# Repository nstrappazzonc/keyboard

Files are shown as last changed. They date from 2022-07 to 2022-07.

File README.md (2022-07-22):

# Keyboard Matías

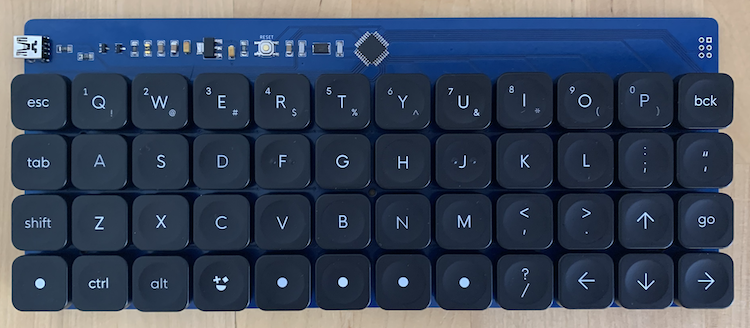
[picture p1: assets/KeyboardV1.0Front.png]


Es mi teclado Ortholinear diseñado y construido por mi, todo el hardware y el diseno es OpenSource (1), la idea de este repositorio es explicarte como se construye uno paso a paso.

1. Los MCU y otros componentes electronicos no son OpenSource.

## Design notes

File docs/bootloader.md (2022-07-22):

# Bootloader

La empresa [Microchip](https://www.microchip.com/) que fabrica el MCU ATmega32U2 que usamos para este proyecto, ofrece un [bootloader](https://www.microchip.com/en-us/product/ATMEGA32U2) que permite la funcionalidad DFU, también otros desarrolladores han hecho su propia versión cómo [Arduino](https://github.com/arduino/ArduinoCore-avr/tree/master/bootloaders) y [lufa](https://github.com/abcminiuser/lufa/tree/master/Bootloaders).

Un DFU quiere decir (Device Firmware Upgrade) y es un mecanismo desarrollado para ser implementado en los MCU, tienen una interfaz de conexión tipo USB para que puedan actualizar el firmware de una forma simple siempre y cuando éste pre-instalado. Con el DFU ya no hace falta flashear usando el ISP u otros medios.

Para tener el DFU en el MCU debemos flashearlo por la interfaz de conexion del ISP, una vez hecho ya no es necesario volver a usar el ISP en situaciones normales.

Para este proyecto, hemos dejado una [copia aquí](https://github.com/nstrappazzonc/keyboard/tree/main/firmware/bootloader).

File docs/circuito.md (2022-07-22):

# Circuito

En la alimentación por el puerto USB se ha implementado un circuito que evita la corriente devuelta (Reverse Current) mediante transistores MOSFET.

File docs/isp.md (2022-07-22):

# ISP

Significa In System Programmer o In-circuit Serial Programmer, y es una interfaz compuesta de 6 pines para programar el MCU.

ISP Pinout

Usando un [Pocket AVR Programmer](https://www.sparkfun.com/products/9825) podemos flashear el programa de nuestro ordenador al MCU mediante una aplicación llamada [avrdude](https://github.com/avrdudes/avrdude).

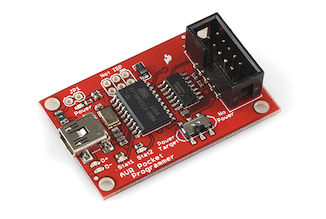
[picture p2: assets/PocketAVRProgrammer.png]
Pocket AVR Programmer


Lo que debe hacer es tener los 6 pines del ISP conectados al MCU de la siguiente forma:

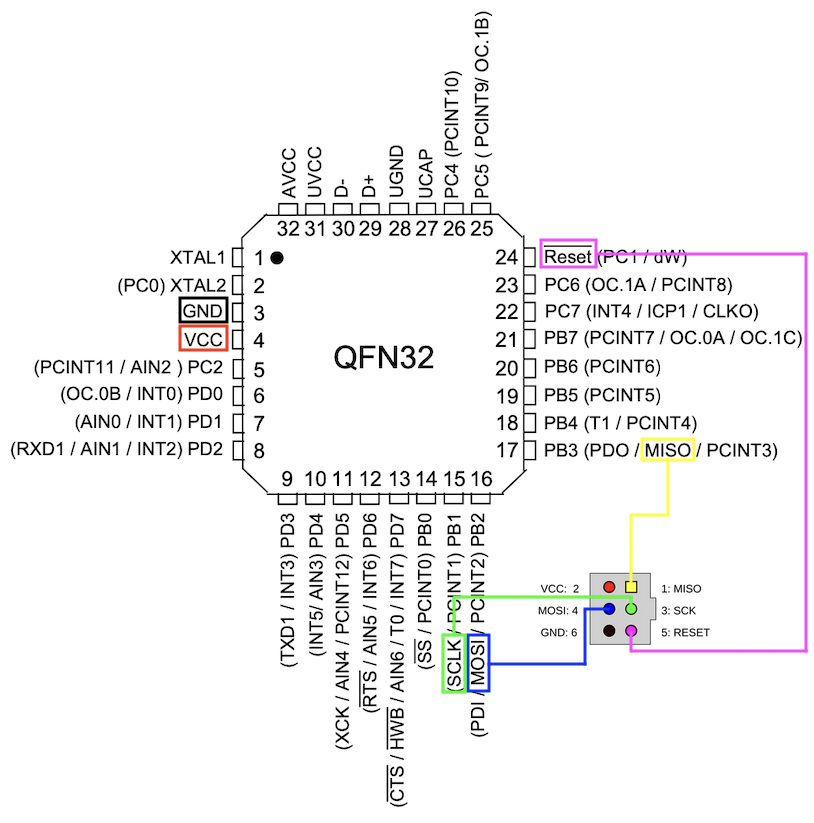
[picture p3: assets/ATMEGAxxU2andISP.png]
MCU & ISP


En MAC OS X y en Linux no hace falta drivers, al hacer `lsusb` me debería salir entre la lista el siguiente ID `1781:0c9f` del device conectado.

```bash
Bus 020 Device 013: ID 1781:0c9f 1781 Vendor-Specific Device
```

Para subir el firmware con el comando `avrdude` lo ejecutamos de la siguiente forma:

```bash
avrdude -c usbtiny -p ATMEGA32U2 -U flash:w:main.hex
```

De todos modos, en el proyecto hemos dejado todo listo dentro del [Makefile](https://github.com/nstrappazzonc/keyboard/blob/main/firmware/bootloader/Makefile) para subir el [DFU](https://github.com/nstrappazzonc/keyboard/blob/main/docs/bootloader.md).

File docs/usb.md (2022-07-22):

# USB

El conector USB instalado en el teclado es de tipo Mini B que esta compuesto de 5 pines, y el tipo de conector es de segunda generación o en su defecto Version 2.0, este tipo de conector soporta un radio de transferencia de 480 Mbps. y soporta un cable de hasta 5 metros de largo, lo cual es más que suficiente para un teclado convencional

Este tipo de conector necesita un cable compuesto de 4 hilos, cada uno tiene un proposito:

|Signal Name|Color |Description|
|---|---|---|
|GND |Negro |Ground |
|VCC |Rojo  |+5v |
|D+ / Dp |Verde |Data+ |
|D- / Dn |Blanco|Data- |

Cada extremo se conecta por igual, si el cable verde es D+ en uno de los extremos, tambien del otro extremo sigue siendo D-, no es cómo en otros protocolos que se invierte.

Las partes del cable tienen diferentes nombres, cada quien lo traduce o le asigna un nombre según la marca, pero es bastante intuitio:

1. **Cubierta del cable:** Llevan una cubierta de recubrimiento exterior de protección, por lo general son de material polimérico.
2. **Protección metalica:** Pueden estar compuesta de dos niveles, ambas de aluminio, ambos están desnudos a propósito, para que haga contacto entre ellos, cada uno tiene un proposito y juntas otro proposito:
    1. El trenzado es un blindaje mecanico que proteje el cable de agreciones externas; animales, golpes, etc.
    2. La pantalla es un aislante de las senales que pasan por el interior.
    3. Ambas protecciones tienen un uso adicional y es opcional en nuestro caso, el cual permite ser una conexion a tierra o una via de descarga electroestatica (ESD), donde el trenzado por su naturaleza debe conectarse (engarzado o soldado) a la carcasa metálica del receptáculo/enchufe USB al final del cable.
3. **Hilos:** Es el conductor de la senal, es un cable multifilar de cobre.

## Pinout

### USB Mini B Pinout:

| Male | Female |
|---|---|
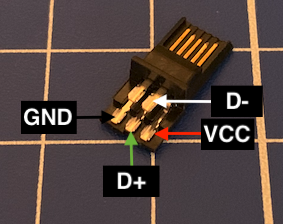
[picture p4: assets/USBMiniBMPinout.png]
USB Mini B Pinout
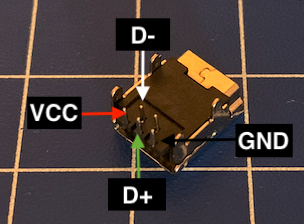
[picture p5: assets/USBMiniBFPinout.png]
USB Mini B Pinout
|||

### USB C Pinout:

| Male |
|------|
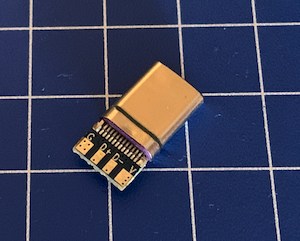
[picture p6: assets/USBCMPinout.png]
USB Mini B Pinout
||

Generalmente los conectores de este tipo ya viene impreso el significado del pin.

## Soldar

Leer los consejos antes de continuar, de esta forma podrás crear tu propio cable con mas facilidad y seguridad.

0. Revisar el estado de los cables y conectores, que no esten occidados.
1. Ir soldando los cables de adentro hacia afuera.
2. Probar con un tester:
    1. Cada pin de extremo a extremo si hay contacto antes de soldar.
    2. Cada pin de un extremo con todos los pines del extremo para identificar si hay un corto.
    3. Conectar el cable y verificar si VCC y GND están bien.

La camisa metalica del cable se conecta junto a GNC.
Hay ordenadores, como los Mac, donde puede que el cable no sea reconocido, pero en otros si.

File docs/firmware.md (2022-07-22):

# Firmware

Para ahorrar el proceso de desarrollo, y por la compatibilidad que tiene el MCU utilizado, opté por usar el proyecto [QMK (Quantum Mechanical Keyboard Firmware)](https://github.com/qmk/qmk_firmware/) para configurar el hardware. De lo contrario, habían dos opciones; programar el AVR usando C y C++, y para gestionar la comunicación del protocolo USB se puede usar una librería muy famosa llamada [lufa (Lightweight USB Framework for AVRs)](https://github.com/abcminiuser/lufa) que tambien lo usa QMK.

Con el siguiente comando subes el firmware al MCU.

```bash
qmk flash -kb nstrappazzonc -km default
```

Te preguntará para que presiones el botón RESET del teclado para que el DFU entre en modo para grabar.

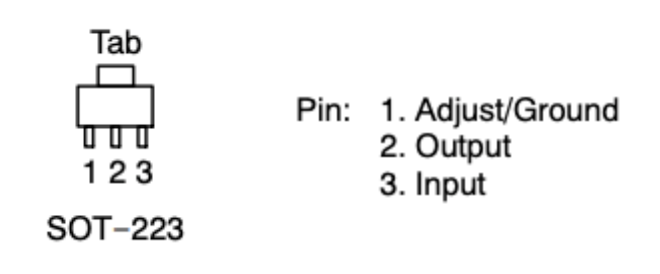
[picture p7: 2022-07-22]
assets/NCP1117Pinout.png

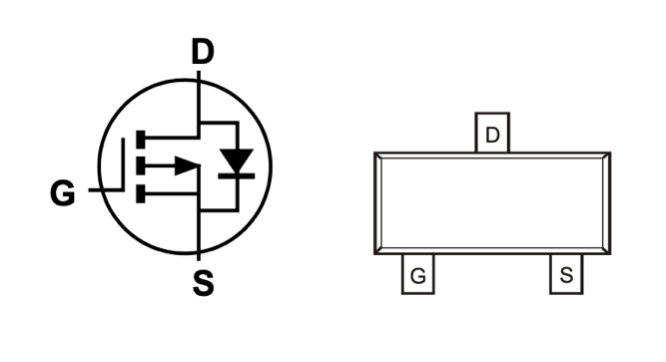
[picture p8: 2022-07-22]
assets/DMG2305UXPinout.png

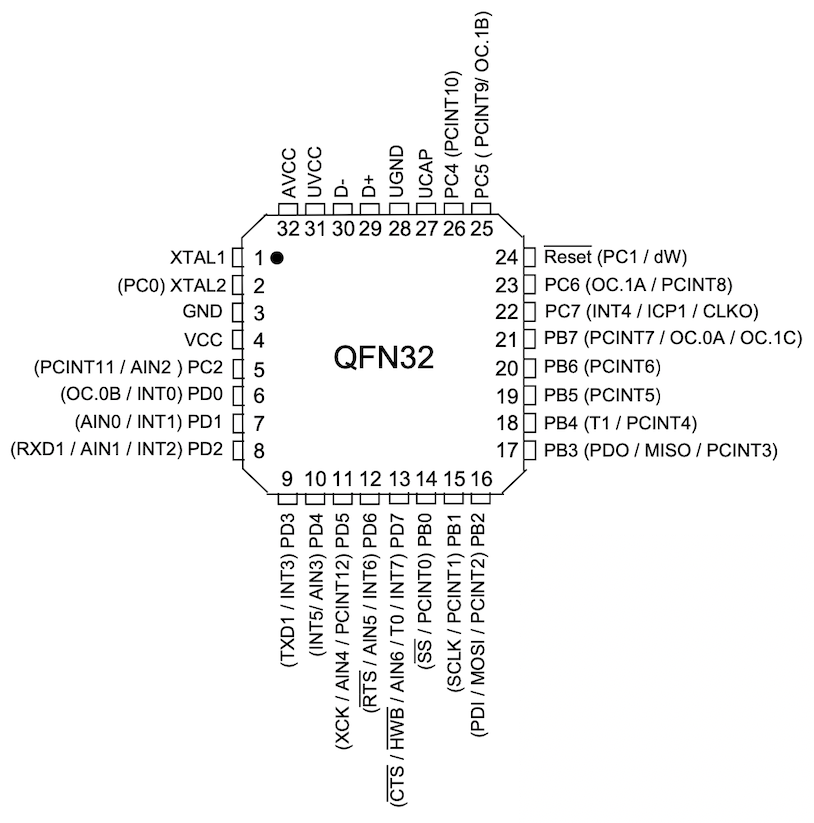
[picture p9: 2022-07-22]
assets/ATMEGAxxU2Pinout.png

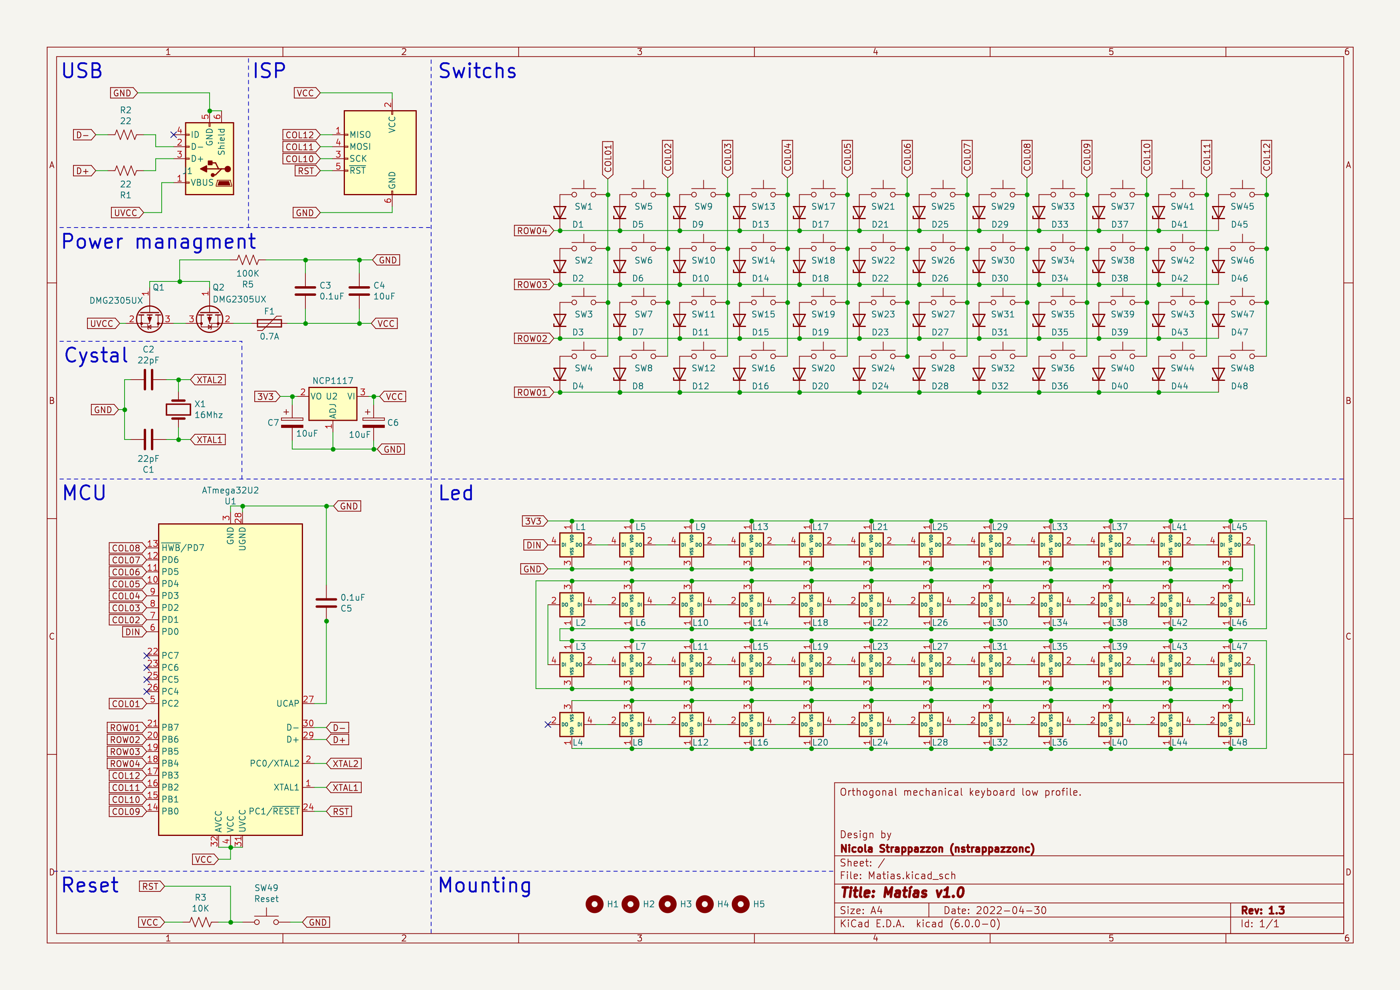
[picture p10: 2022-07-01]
assets/schematicv10.png

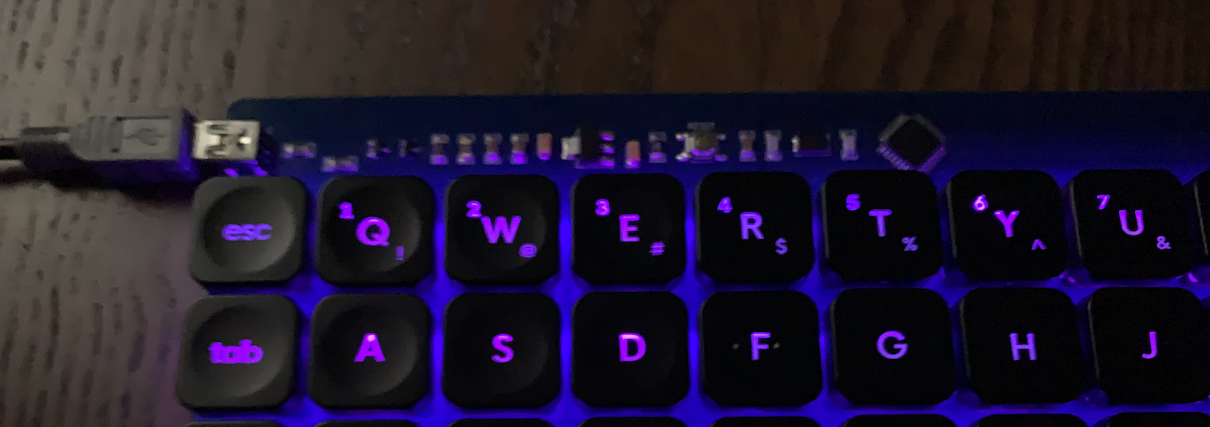
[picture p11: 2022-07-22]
assets/header.png

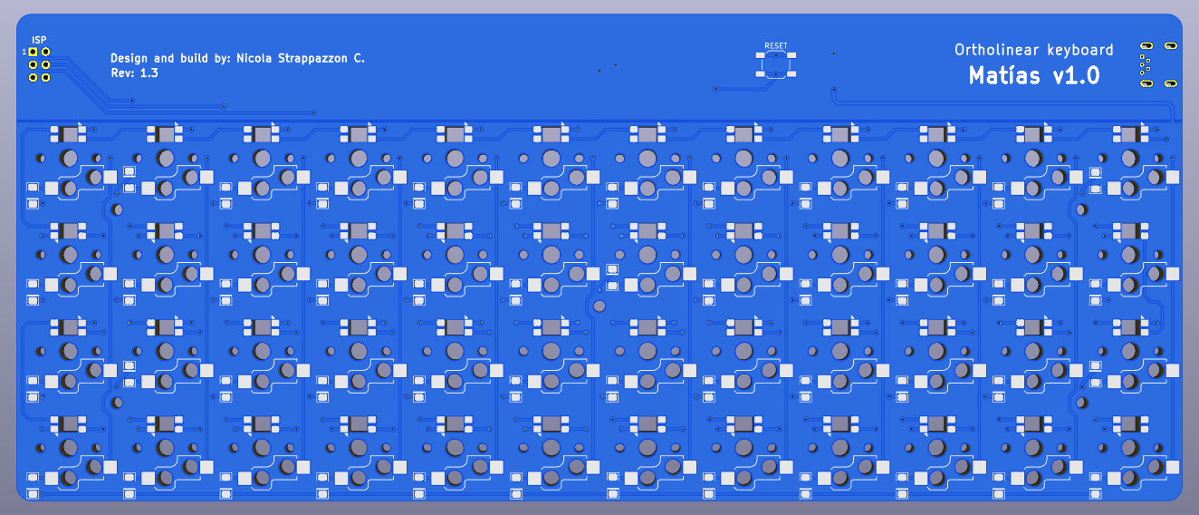
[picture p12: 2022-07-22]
assets/MatiasV1Back.png

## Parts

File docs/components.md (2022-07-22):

# Lista de recursos

A continuación listamos todos los componentes, materiales y herramientas necesarios para la construcción del teclado, según la cantidad, el proveedor y la calidad influyen en los precios, también otro factor es la escases de los ATMega (MCU) por el COVID:

## BOM (Bill of Materials)

Es una lista de componentes necesarios para el ensamblaje de la tarjeta PCB. Para este caso asociamos cada componente con el enlace del vendedor recomendado.

| Qty. | Reference(s) | Value | Description |
|---|---|---|---|
| 2 | C1, C2 | 22pF  | |
| 2 | C3, C5 | 0.1uF | |
| 1 | C4	 | 10uF  | |
| 2 | C6, C7	 | 10uF  | |
| 48 | D1-D48 | | 1N47xxA |
| 1	 | F1 | 0.7A  | |
| 1	 | ISP1 | | Header male 2.54 2x3  |
| 1	 | J1 | | USB Type B Mini |
| 48 | L1-L48 | | SK6812MINI |
| 2	 | Q1, Q2	 | | DMG2305UX |
| 2	 | R1, R2	 | 22 | |
| 1	 | R3	 | 10K | |
| 1	 | R5	 | 100K  | |
| 48 | SW1-SW48 | | [Kailh Hot Swap Socket low profile](https://es.aliexpress.com/item/33023283633.html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)|
| 1 | SW49 | | [Switch SMD](https://www.mouser.es/ProductDetail/611-PTS526SK15SMR2L) |
| 1 | U1 | | [ATmega32U2](https://www.mouser.es/ProductDetail/Microchip-Technology-Atmel/ATMEGA32U2-AU?qs=rBGENRD8NwKYx79eccv8UA%3D%3D)|
| 1 | U2 | | NCP1117 |
| 1 | X1 | 16Mhz | |

## Componentes adicionales

| Qty. | Description |
|---|---|
| 48 | [Kailh Choc Switch](https://es.aliexpress.com/item/32959996455.html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)|
| 1 | [Work Louder Choc Keycaps - Legend Set](https://worklouder.cc/shop/wrk-legend/)|

## Componentes para el protoboard

- [SMT ADAPTERS 3 PACK 44TQFP/QFN](https://www.digikey.es/es/products/detail/adafruit-industries-llc/1162/5022793).
- [ADAFRUIT USB C BREAKOUT BOARD](https://www.digikey.es/es/products/detail/adafruit-industries-llc/4090/9951930).
- [ADAPTER MINI KIT BB AVR ISP 6PIN](https://www.digikey.es/es/products/detail/adafruit-industries-llc/1465/5353649).

## Materiales

- [Solder Wick / Malla para desoldar, de 2mm de ancho](https://www.mouser.es/ProductDetail/Chip-Quik/SOLDERWICK2.0?qs=Wj%2FVkw3K%252BMCk2u3J5nP42Q%3D%3D).
- [Estaño para soldar de tipo Sn99 Ag0.3 Cu0.7 de 0.38mm de diametro, su punto de fusión es de 217 ℃.](https://www.digikey.es/es/products/detail/chip-quik-inc/SMD2SWLF-015-1OZ/9558156)
- [Flux liquido a base de agua](https://www.amazon.es/JBC-548074021-Flux-soldadura-Fl-15/dp/B00CIOVF8W).

## Herramientas

Recomiendo ampliamente el uso de estas herramientas:

- [Estación de soldadura](https://www.amazon.es/dp/B00EK7TE2E).
- [Estación de aire caliente](https://www.amazon.es/gp/product/B07SD1WXYB).
- Multímetro.
- [Pinzas ESD](https://www.amazon.es/gp/product/B081VNKHNH).
- [Gafas de aumento](https://www.digikey.es/es/products/detail/aven-tools/26224/5306726).
- [Soporte](https://omnifixo.com).
- [Corta cables](https://www.amazon.es/gp/product/B06XG9T9X2).
- [Alicate punta fina](https://www.amazon.es/gp/product/B0032V1A44).
- Pelacables.
- [Pocket AVR Programmer](https://www.sparkfun.com/products/9825).
- [ISP Conector 2x3 de 2.54mm](https://www.aliexpress.com/item/1005001625917931.html?spm=a2g0o.cart.0.0.150f38daS8oLTL&mp=1).
- [Protoboard](https://www.digikey.es/es/products/detail/global-specialties/PB-83M/8134127).

## Proveedores

- [Digi-Key](https://www.digikey.es)
- [Mouser](https://mouser.es)
- [AliExpress](https://www.aliexpress.com) Dejar este sitio cómo la última opción.

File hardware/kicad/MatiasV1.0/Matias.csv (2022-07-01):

Source: | /Users/nsc/Dropbox/SourceCodes/keyboard/hardware/kicad/Matias/Matias.kicad_sch
Date: | 2022 July 01, Friday 18:37:17
Tool: | Eeschema (6.0.0-0)
Generator: | /Applications/KiCad/KiCad.app/Contents/SharedSupport/plugins/bom_csv_grouped_by_value.py
Component Count: | 164
Individual Components:
Item | Qty | Reference(s) | Value | LibPart | Footprint | Datasheet
 |  | C1 | 22pF | Device:C | MyLibrary:C1206 | ~
 |  | C2 | 22pF | Device:C | MyLibrary:C1206 | ~
 |  | C3 | 0.1uF | Device:C | MyLibrary:C1206 | ~
 |  | C4 | 10uF | Device:C | MyLibrary:C1206 | ~
 |  | C5 | 0.1uF | Device:C | MyLibrary:C1206 | ~
 |  | C6 | 10uF | Device:C_Polarized | Capacitor_Tantalum_SMD:CP_EIA-3216-18_Kemet-A | ~
 |  | C7 | 10uF | Device:C_Polarized | Capacitor_Tantalum_SMD:CP_EIA-3216-18_Kemet-A | ~
 |  | D1 | 1N47xxA | Diode:1N47xxA | MyLibrary:D1206 | https://www.vishay.com/docs/85816/1n4728a.pdf
 |  | D2 | 1N47xxA | Diode:1N47xxA | MyLibrary:D1206 | https://www.vishay.com/docs/85816/1n4728a.pdf
 |  | D3 | 1N47xxA | Diode:1N47xxA | MyLibrary:D1206 | https://www.vishay.com/docs/85816/1n4728a.pdf
 |  | D4 | 1N47xxA | Diode:1N47xxA | MyLibrary:D1206 | https://www.vishay.com/docs/85816/1n4728a.pdf
 |  | D5 | 1N47xxA | Diode:1N47xxA | MyLibrary:D1206 | https://www.vishay.com/docs/85816/1n4728a.pdf
 |  | D6 | 1N47xxA | Diode:1N47xxA | MyLibrary:D1206 | https://www.vishay.com/docs/85816/1n4728a.pdf
 |  | D7 | 1N47xxA | Diode:1N47xxA | MyLibrary:D1206 | https://www.vishay.com/docs/85816/1n4728a.pdf
 |  | D8 | 1N47xxA | Diode:1N47xxA | MyLibrary:D1206 | https://www.vishay.com/docs/85816/1n4728a.pdf
 |  | D9 | 1N47xxA | Diode:1N47xxA | MyLibrary:D1206 | https://www.vishay.com/docs/85816/1n4728a.pdf
 |  | D10 | 1N47xxA | Diode:1N47xxA | MyLibrary:D1206 | https://www.vishay.com/docs/85816/1n4728a.pdf
 |  | D11 | 1N47xxA | Diode:1N47xxA | MyLibrary:D1206 | https://www.vishay.com/docs/85816/1n4728a.pdf
 |  | D12 | 1N47xxA | Diode:1N47xxA | MyLibrary:D1206 | https://www.vishay.com/docs/85816/1n4728a.pdf
 |  | D13 | 1N47xxA | Diode:1N47xxA | MyLibrary:D1206 | https://www.vishay.com/docs/85816/1n4728a.pdf
 |  | D14 | 1N47xxA | Diode:1N47xxA | MyLibrary:D1206 | https://www.vishay.com/docs/85816/1n4728a.pdf
 |  | D15 | 1N47xxA | Diode:1N47xxA | MyLibrary:D1206 | https://www.vishay.com/docs/85816/1n4728a.pdf
 |  | D16 | 1N47xxA | Diode:1N47xxA | MyLibrary:D1206 | https://www.vishay.com/docs/85816/1n4728a.pdf
 |  | D17 | 1N47xxA | Diode:1N47xxA | MyLibrary:D1206 | https://www.vishay.com/docs/85816/1n4728a.pdf
 |  | D18 | 1N47xxA | Diode:1N47xxA | MyLibrary:D1206 | https://www.vishay.com/docs/85816/1n4728a.pdf
 |  | D19 | 1N47xxA | Diode:1N47xxA | MyLibrary:D1206 | https://www.vishay.com/docs/85816/1n4728a.pdf
 |  | D20 | 1N47xxA | Diode:1N47xxA | MyLibrary:D1206 | https://www.vishay.com/docs/85816/1n4728a.pdf
 |  | D21 | 1N47xxA | Diode:1N47xxA | MyLibrary:D1206 | https://www.vishay.com/docs/85816/1n4728a.pdf
 |  | D22 | 1N47xxA | Diode:1N47xxA | MyLibrary:D1206 | https://www.vishay.com/docs/85816/1n4728a.pdf
 |  | D23 | 1N47xxA | Diode:1N47xxA | MyLibrary:D1206 | https://www.vishay.com/docs/85816/1n4728a.pdf
 |  | D24 | 1N47xxA | Diode:1N47xxA | MyLibrary:D1206 | https://www.vishay.com/docs/85816/1n4728a.pdf
 |  | D25 | 1N47xxA | Diode:1N47xxA | MyLibrary:D1206 | https://www.vishay.com/docs/85816/1n4728a.pdf
 |  | D26 | 1N47xxA | Diode:1N47xxA | MyLibrary:D1206 | https://www.vishay.com/docs/85816/1n4728a.pdf
 |  | D27 | 1N47xxA | Diode:1N47xxA | MyLibrary:D1206 | https://www.vishay.com/docs/85816/1n4728a.pdf
 |  | D28 | 1N47xxA | Diode:1N47xxA | MyLibrary:D1206 | https://www.vishay.com/docs/85816/1n4728a.pdf
 |  | D29 | 1N47xxA | Diode:1N47xxA | MyLibrary:D1206 | https://www.vishay.com/docs/85816/1n4728a.pdf
 |  | D30 | 1N47xxA | Diode:1N47xxA | MyLibrary:D1206 | https://www.vishay.com/docs/85816/1n4728a.pdf
 |  | D31 | 1N47xxA | Diode:1N47xxA | MyLibrary:D1206 | https://www.vishay.com/docs/85816/1n4728a.pdf
 |  | D32 | 1N47xxA | Diode:1N47xxA | MyLibrary:D1206 | https://www.vishay.com/docs/85816/1n4728a.pdf
 |  | D33 | 1N47xxA | Diode:1N47xxA | MyLibrary:D1206 | https://www.vishay.com/docs/85816/1n4728a.pdf
 |  | D34 | 1N47xxA | Diode:1N47xxA | MyLibrary:D1206 | https://www.vishay.com/docs/85816/1n4728a.pdf
 |  | D35 | 1N47xxA | Diode:1N47xxA | MyLibrary:D1206 | https://www.vishay.com/docs/85816/1n4728a.pdf
 |  | D36 | 1N47xxA | Diode:1N47xxA | MyLibrary:D1206 | https://www.vishay.com/docs/85816/1n4728a.pdf
 |  | D37 | 1N47xxA | Diode:1N47xxA | MyLibrary:D1206 | https://www.vishay.com/docs/85816/1n4728a.pdf
 |  | D38 | 1N47xxA | Diode:1N47xxA | MyLibrary:D1206 | https://www.vishay.com/docs/85816/1n4728a.pdf
 |  | D39 | 1N47xxA | Diode:1N47xxA | MyLibrary:D1206 | https://www.vishay.com/docs/85816/1n4728a.pdf
 |  | D40 | 1N47xxA | Diode:1N47xxA | MyLibrary:D1206 | https://www.vishay.com/docs/85816/1n4728a.pdf
 |  | D41 | 1N47xxA | Diode:1N47xxA | MyLibrary:D1206 | https://www.vishay.com/docs/85816/1n4728a.pdf
 |  | D42 | 1N47xxA | Diode:1N47xxA | MyLibrary:D1206 | https://www.vishay.com/docs/85816/1n4728a.pdf
 |  | D43 | 1N47xxA | Diode:1N47xxA | MyLibrary:D1206 | https://www.vishay.com/docs/85816/1n4728a.pdf
 |  | D44 | 1N47xxA | Diode:1N47xxA | MyLibrary:D1206 | https://www.vishay.com/docs/85816/1n4728a.pdf
 |  | D45 | 1N47xxA | Diode:1N47xxA | MyLibrary:D1206 | https://www.vishay.com/docs/85816/1n4728a.pdf
 |  | D46 | 1N47xxA | Diode:1N47xxA | MyLibrary:D1206 | https://www.vishay.com/docs/85816/1n4728a.pdf
 |  | D47 | 1N47xxA | Diode:1N47xxA | MyLibrary:D1206 | https://www.vishay.com/docs/85816/1n4728a.pdf
 |  | D48 | 1N47xxA | Diode:1N47xxA | MyLibrary:D1206 | https://www.vishay.com/docs/85816/1n4728a.pdf
 |  | F1 | 0.7A | Device:Polyfuse | MyLibrary:R1206 | ~
 |  | ISP1 | AVR-ISP-6 | Connector:AVR-ISP-6 | MyLibrary:ISP | ~
 |  | J1 | USB Type B Mini | Connector:USB_B_Mini | Library:USB_Micro-B | ~
 |  | L1 | SK6812MINI | Library:SK6812MINI | MyLibrary:SK6812-MINI-E | https://cdn-shop.adafruit.com/product-files/2686/SK6812MINI_REV.01-1-2.pdf
 |  | L2 | SK6812MINI | Library:SK6812MINI | MyLibrary:SK6812-MINI-E | https://cdn-shop.adafruit.com/product-files/2686/SK6812MINI_REV.01-1-2.pdf
 |  | L3 | SK6812MINI | Library:SK6812MINI | MyLibrary:SK6812-MINI-E | https://cdn-shop.adafruit.com/product-files/2686/SK6812MINI_REV.01-1-2.pdf
 |  | L4 | SK6812MINI | Library:SK6812MINI | MyLibrary:SK6812-MINI-E | https://cdn-shop.adafruit.com/product-files/2686/SK6812MINI_REV.01-1-2.pdf
 |  | L5 | SK6812MINI | Library:SK6812MINI | MyLibrary:SK6812-MINI-E | https://cdn-shop.adafruit.com/product-files/2686/SK6812MINI_REV.01-1-2.pdf
 |  | L6 | SK6812MINI | Library:SK6812MINI | MyLibrary:SK6812-MINI-E | https://cdn-shop.adafruit.com/product-files/2686/SK6812MINI_REV.01-1-2.pdf
 |  | L7 | SK6812MINI | Library:SK6812MINI | MyLibrary:SK6812-MINI-E | https://cdn-shop.adafruit.com/product-files/2686/SK6812MINI_REV.01-1-2.pdf
 |  | L8 | SK6812MINI | Library:SK6812MINI | MyLibrary:SK6812-MINI-E | https://cdn-shop.adafruit.com/product-files/2686/SK6812MINI_REV.01-1-2.pdf
 |  | L9 | SK6812MINI | Library:SK6812MINI | MyLibrary:SK6812-MINI-E | https://cdn-shop.adafruit.com/product-files/2686/SK6812MINI_REV.01-1-2.pdf
 |  | L10 | SK6812MINI | Library:SK6812MINI | MyLibrary:SK6812-MINI-E | https://cdn-shop.adafruit.com/product-files/2686/SK6812MINI_REV.01-1-2.pdf
 |  | L11 | SK6812MINI | Library:SK6812MINI | MyLibrary:SK6812-MINI-E | https://cdn-shop.adafruit.com/product-files/2686/SK6812MINI_REV.01-1-2.pdf
 |  | L12 | SK6812MINI | Library:SK6812MINI | MyLibrary:SK6812-MINI-E | https://cdn-shop.adafruit.com/product-files/2686/SK6812MINI_REV.01-1-2.pdf
 |  | L13 | SK6812MINI | Library:SK6812MINI | MyLibrary:SK6812-MINI-E | https://cdn-shop.adafruit.com/product-files/2686/SK6812MINI_REV.01-1-2.pdf
 |  | L14 | SK6812MINI | Library:SK6812MINI | MyLibrary:SK6812-MINI-E | https://cdn-shop.adafruit.com/product-files/2686/SK6812MINI_REV.01-1-2.pdf
 |  | L15 | SK6812MINI | Library:SK6812MINI | MyLibrary:SK6812-MINI-E | https://cdn-shop.adafruit.com/product-files/2686/SK6812MINI_REV.01-1-2.pdf
 |  | L16 | SK6812MINI | Library:SK6812MINI | MyLibrary:SK6812-MINI-E | https://cdn-shop.adafruit.com/product-files/2686/SK6812MINI_REV.01-1-2.pdf
 |  | L17 | SK6812MINI | Library:SK6812MINI | MyLibrary:SK6812-MINI-E | https://cdn-shop.adafruit.com/product-files/2686/SK6812MINI_REV.01-1-2.pdf
 |  | L18 | SK6812MINI | Library:SK6812MINI | MyLibrary:SK6812-MINI-E | https://cdn-shop.adafruit.com/product-files/2686/SK6812MINI_REV.01-1-2.pdf
 |  | L19 | SK6812MINI | Library:SK6812MINI | MyLibrary:SK6812-MINI-E | https://cdn-shop.adafruit.com/product-files/2686/SK6812MINI_REV.01-1-2.pdf
 |  | L20 | SK6812MINI | Library:SK6812MINI | MyLibrary:SK6812-MINI-E | https://cdn-shop.adafruit.com/product-files/2686/SK6812MINI_REV.01-1-2.pdf
 |  | L21 | SK6812MINI | Library:SK6812MINI | MyLibrary:SK6812-MINI-E | https://cdn-shop.adafruit.com/product-files/2686/SK6812MINI_REV.01-1-2.pdf
 |  | L22 | SK6812MINI | Library:SK6812MINI | MyLibrary:SK6812-MINI-E | https://cdn-shop.adafruit.com/product-files/2686/SK6812MINI_REV.01-1-2.pdf
 |  | L23 | SK6812MINI | Library:SK6812MINI | MyLibrary:SK6812-MINI-E | https://cdn-shop.adafruit.com/product-files/2686/SK6812MINI_REV.01-1-2.pdf
 |  | L24 | SK6812MINI | Library:SK6812MINI | MyLibrary:SK6812-MINI-E | https://cdn-shop.adafruit.com/product-files/2686/SK6812MINI_REV.01-1-2.pdf
 |  | L25 | SK6812MINI | Library:SK6812MINI | MyLibrary:SK6812-MINI-E | https://cdn-shop.adafruit.com/product-files/2686/SK6812MINI_REV.01-1-2.pdf
 |  | L26 | SK6812MINI | Library:SK6812MINI | MyLibrary:SK6812-MINI-E | https://cdn-shop.adafruit.com/product-files/2686/SK6812MINI_REV.01-1-2.pdf
 |  | L27 | SK6812MINI | Library:SK6812MINI | MyLibrary:SK6812-MINI-E | https://cdn-shop.adafruit.com/product-files/2686/SK6812MINI_REV.01-1-2.pdf
 |  | L28 | SK6812MINI | Library:SK6812MINI | MyLibrary:SK6812-MINI-E | https://cdn-shop.adafruit.com/product-files/2686/SK6812MINI_REV.01-1-2.pdf
 |  | L29 | SK6812MINI | Library:SK6812MINI | MyLibrary:SK6812-MINI-E | https://cdn-shop.adafruit.com/product-files/2686/SK6812MINI_REV.01-1-2.pdf
 |  | L30 | SK6812MINI | Library:SK6812MINI | MyLibrary:SK6812-MINI-E | https://cdn-shop.adafruit.com/product-files/2686/SK6812MINI_REV.01-1-2.pdf
 |  | L31 | SK6812MINI | Library:SK6812MINI | MyLibrary:SK6812-MINI-E | https://cdn-shop.adafruit.com/product-files/2686/SK6812MINI_REV.01-1-2.pdf
 |  | L32 | SK6812MINI | Library:SK6812MINI | MyLibrary:SK6812-MINI-E | https://cdn-shop.adafruit.com/product-files/2686/SK6812MINI_REV.01-1-2.pdf
 |  | L33 | SK6812MINI | Library:SK6812MINI | MyLibrary:SK6812-MINI-E | https://cdn-shop.adafruit.com/product-files/2686/SK6812MINI_REV.01-1-2.pdf
 |  | L34 | SK6812MINI | Library:SK6812MINI | MyLibrary:SK6812-MINI-E | https://cdn-shop.adafruit.com/product-files/2686/SK6812MINI_REV.01-1-2.pdf
 |  | L35 | SK6812MINI | Library:SK6812MINI | MyLibrary:SK6812-MINI-E | https://cdn-shop.adafruit.com/product-files/2686/SK6812MINI_REV.01-1-2.pdf
 |  | L36 | SK6812MINI | Library:SK6812MINI | MyLibrary:SK6812-MINI-E | https://cdn-shop.adafruit.com/product-files/2686/SK6812MINI_REV.01-1-2.pdf
 |  | L37 | SK6812MINI | Library:SK6812MINI | MyLibrary:SK6812-MINI-E | https://cdn-shop.adafruit.com/product-files/2686/SK6812MINI_REV.01-1-2.pdf
 |  | L38 | SK6812MINI | Library:SK6812MINI | MyLibrary:SK6812-MINI-E | https://cdn-shop.adafruit.com/product-files/2686/SK6812MINI_REV.01-1-2.pdf
 |  | L39 | SK6812MINI | Library:SK6812MINI | MyLibrary:SK6812-MINI-E | https://cdn-shop.adafruit.com/product-files/2686/SK6812MINI_REV.01-1-2.pdf
 |  | L40 | SK6812MINI | Library:SK6812MINI | MyLibrary:SK6812-MINI-E | https://cdn-shop.adafruit.com/product-files/2686/SK6812MINI_REV.01-1-2.pdf
 |  | L41 | SK6812MINI | Library:SK6812MINI | MyLibrary:SK6812-MINI-E | https://cdn-shop.adafruit.com/product-files/2686/SK6812MINI_REV.01-1-2.pdf
 |  | L42 | SK6812MINI | Library:SK6812MINI | MyLibrary:SK6812-MINI-E | https://cdn-shop.adafruit.com/product-files/2686/SK6812MINI_REV.01-1-2.pdf
 |  | L43 | SK6812MINI | Library:SK6812MINI | MyLibrary:SK6812-MINI-E | https://cdn-shop.adafruit.com/product-files/2686/SK6812MINI_REV.01-1-2.pdf
 |  | L44 | SK6812MINI | Library:SK6812MINI | MyLibrary:SK6812-MINI-E | https://cdn-shop.adafruit.com/product-files/2686/SK6812MINI_REV.01-1-2.pdf
 |  | L45 | SK6812MINI | Library:SK6812MINI | MyLibrary:SK6812-MINI-E | https://cdn-shop.adafruit.com/product-files/2686/SK6812MINI_REV.01-1-2.pdf
 |  | L46 | SK6812MINI | Library:SK6812MINI | MyLibrary:SK6812-MINI-E | https://cdn-shop.adafruit.com/product-files/2686/SK6812MINI_REV.01-1-2.pdf
 |  | L47 | SK6812MINI | Library:SK6812MINI | MyLibrary:SK6812-MINI-E | https://cdn-shop.adafruit.com/product-files/2686/SK6812MINI_REV.01-1-2.pdf
 |  | L48 | SK6812MINI | Library:SK6812MINI | MyLibrary:SK6812-MINI-E | https://cdn-shop.adafruit.com/product-files/2686/SK6812MINI_REV.01-1-2.pdf
 |  | Q1 | DMG2305UX | Transistor_FET:AO3401A | Package_TO_SOT_SMD:SOT-23 | http://www.aosmd.com/pdfs/datasheet/AO3401A.pdf
 |  | Q2 | DMG2305UX | Transistor_FET:AO3401A | Package_TO_SOT_SMD:SOT-23 | http://www.aosmd.com/pdfs/datasheet/AO3401A.pdf
 |  | R1 | 22 | Device:R_US | MyLibrary:R1206 | ~
 |  | R2 | 22 | Device:R_US | MyLibrary:R1206 | ~
 |  | R3 | 10K | Device:R_US | MyLibrary:R1206 | ~
 |  | R5 | 100K | Device:R_US | MyLibrary:R1206 | ~
 |  | SW1 | Push | Switch:SW_Push | Library:Kailh_socket_PG1350 | ~
 |  | SW2 | Push | Switch:SW_Push | Library:Kailh_socket_PG1350 | ~
 |  | SW3 | Push | Switch:SW_Push | Library:Kailh_socket_PG1350 | ~
 |  | SW4 | Push | Switch:SW_Push | Library:Kailh_socket_PG1350 | ~
 |  | SW5 | Push | Switch:SW_Push | Library:Kailh_socket_PG1350 | ~
 |  | SW6 | Push | Switch:SW_Push | Library:Kailh_socket_PG1350 | ~
 |  | SW7 | Push | Switch:SW_Push | Library:Kailh_socket_PG1350 | ~
 |  | SW8 | Push | Switch:SW_Push | Library:Kailh_socket_PG1350 | ~
 |  | SW9 | Push | Switch:SW_Push | Library:Kailh_socket_PG1350 | ~
 |  | SW10 | Push | Switch:SW_Push | Library:Kailh_socket_PG1350 | ~
 |  | SW11 | Push | Switch:SW_Push | Library:Kailh_socket_PG1350 | ~
 |  | SW12 | Push | Switch:SW_Push | Library:Kailh_socket_PG1350 | ~
 |  | SW13 | Push | Switch:SW_Push | Library:Kailh_socket_PG1350 | ~
 |  | SW14 | Push | Switch:SW_Push | Library:Kailh_socket_PG1350 | ~
 |  | SW15 | Push | Switch:SW_Push | Library:Kailh_socket_PG1350 | ~
 |  | SW16 | Push | Switch:SW_Push | Library:Kailh_socket_PG1350 | ~
 |  | SW17 | Push | Switch:SW_Push | Library:Kailh_socket_PG1350 | ~
 |  | SW18 | Push | Switch:SW_Push | Library:Kailh_socket_PG1350 | ~
 |  | SW19 | Push | Switch:SW_Push | Library:Kailh_socket_PG1350 | ~
 |  | SW20 | Push | Switch:SW_Push | Library:Kailh_socket_PG1350 | ~
 |  | SW21 | Push | Switch:SW_Push | Library:Kailh_socket_PG1350 | ~
 |  | SW22 | Push | Switch:SW_Push | Library:Kailh_socket_PG1350 | ~
 |  | SW23 | Push | Switch:SW_Push | Library:Kailh_socket_PG1350 | ~
 |  | SW24 | Push | Switch:SW_Push | Library:Kailh_socket_PG1350 | ~
 |  | SW25 | Push | Switch:SW_Push | Library:Kailh_socket_PG1350 | ~
 |  | SW26 | Push | Switch:SW_Push | Library:Kailh_socket_PG1350 | ~
 |  | SW27 | Push | Switch:SW_Push | Library:Kailh_socket_PG1350 | ~
 |  | SW28 | Push | Switch:SW_Push | Library:Kailh_socket_PG1350 | ~
 |  | SW29 | Push | Switch:SW_Push | Library:Kailh_socket_PG1350 | ~
 |  | SW30 | Push | Switch:SW_Push | Library:Kailh_socket_PG1350 | ~
 |  | SW31 | Push | Switch:SW_Push | Library:Kailh_socket_PG1350 | ~
 |  | SW32 | Push | Switch:SW_Push | Library:Kailh_socket_PG1350 | ~
 |  | SW33 | Push | Switch:SW_Push | Library:Kailh_socket_PG1350 | ~
 |  | SW34 | Push | Switch:SW_Push | Library:Kailh_socket_PG1350 | ~
 |  | SW35 | Push | Switch:SW_Push | Library:Kailh_socket_PG1350 | ~
 |  | SW36 | Push | Switch:SW_Push | Library:Kailh_socket_PG1350 | ~
 |  | SW37 | Push | Switch:SW_Push | Library:Kailh_socket_PG1350 | ~
 |  | SW38 | Push | Switch:SW_Push | Library:Kailh_socket_PG1350 | ~
 |  | SW39 | Push | Switch:SW_Push | Library:Kailh_socket_PG1350 | ~
 |  | SW40 | Push | Switch:SW_Push | Library:Kailh_socket_PG1350 | ~
 |  | SW41 | Push | Switch:SW_Push | Library:Kailh_socket_PG1350 | ~
 |  | SW42 | Push | Switch:SW_Push | Library:Kailh_socket_PG1350 | ~
 |  | SW43 | Push | Switch:SW_Push | Library:Kailh_socket_PG1350 | ~
 |  | SW44 | Push | Switch:SW_Push | Library:Kailh_socket_PG1350 | ~
 |  | SW45 | Push | Switch:SW_Push | Library:Kailh_socket_PG1350 | ~
 |  | SW46 | Push | Switch:SW_Push | Library:Kailh_socket_PG1350 | ~
 |  | SW47 | Push | Switch:SW_Push | Library:Kailh_socket_PG1350 | ~
 |  | SW48 | Push | Switch:SW_Push | Library:Kailh_socket_PG1350 | ~
 |  | SW49 | Reset | Switch:SW_Push | Button_Switch_SMD:SW_SPST_SKQG_WithStem | ~
 |  | U1 | ATmega32U2 | MCU_Microchip_ATmega:ATmega32U2-A | Package_QFP:TQFP-32_7x7mm_P0.8mm | http://ww1.microchip.com/downloads/en/DeviceDoc/doc7799.pdf
 |  | U2 | NCP1117 | Regulator_Linear:LM337_SOT223 | Package_TO_SOT_SMD:SOT-223
 |  | X1 | 16Mhz | Device:Crystal | Crystal:Crystal_SMD_5032-2Pin_5.0x3.2mm | ~
Collated Components:
Item | Qty | Reference(s) | Value | LibPart | Footprint | Datasheet
1 | 2 | C1, C2 | 22pF | Device:C | MyLibrary:C1206 | ~
2 | 2 | C3, C5 | 0.1uF | Device:C | MyLibrary:C1206 | ~
3 | 1 | C4 | 10uF | Device:C | MyLibrary:C1206 | ~
4 | 2 | C6, C7 | 10uF | Device:C_Polarized | Capacitor_Tantalum_SMD:CP_EIA-3216-18_Kemet-A | ~
5 | 48 | D1, D2, D3, D4, D5, D6, D7, D8, D9, D10, D11, D12, D13, D14, D15, D16, D17, D18, D19, D20, D21, D22, D23, D24, D25, D26, D27, D28, D29, D30, D31, D32, D33, D34, D35, D36, D37, D38, D39, D40, D41, D42, D43, D44, D45, D46, D47, D48 | 1N47xxA | Diode:1N47xxA | MyLibrary:D1206 | https://www.vishay.com/docs/85816/1n4728a.pdf
6 | 1 | F1 | 0.7A | Device:Polyfuse | MyLibrary:R1206 | ~
7 | 1 | ISP1 | AVR-ISP-6 | Connector:AVR-ISP-6 | MyLibrary:ISP | ~
8 | 1 | J1 | USB Type B Mini | Connector:USB_B_Mini | Library:USB_Micro-B | ~
9 | 48 | L1, L2, L3, L4, L5, L6, L7, L8, L9, L10, L11, L12, L13, L14, L15, L16, L17, L18, L19, L20, L21, L22, L23, L24, L25, L26, L27, L28, L29, L30, L31, L32, L33, L34, L35, L36, L37, L38, L39, L40, L41, L42, L43, L44, L45, L46, L47, L48 | SK6812MINI | Library:SK6812MINI | MyLibrary:SK6812-MINI-E | https://cdn-shop.adafruit.com/product-files/2686/SK6812MINI_REV.01-1-2.pdf
10 | 2 | Q1, Q2 | DMG2305UX | Transistor_FET:AO3401A | Package_TO_SOT_SMD:SOT-23 | http://www.aosmd.com/pdfs/datasheet/AO3401A.pdf
11 | 2 | R1, R2 | 22 | Device:R_US | MyLibrary:R1206 | ~
12 | 1 | R3 | 10K | Device:R_US | MyLibrary:R1206 | ~
13 | 1 | R5 | 100K | Device:R_US | MyLibrary:R1206 | ~
14 | 48 | SW1, SW2, SW3, SW4, SW5, SW6, SW7, SW8, SW9, SW10, SW11, SW12, SW13, SW14, SW15, SW16, SW17, SW18, SW19, SW20, SW21, SW22, SW23, SW24, SW25, SW26, SW27, SW28, SW29, SW30, SW31, SW32, SW33, SW34, SW35, SW36, SW37, SW38, SW39, SW40, SW41, SW42, SW43, SW44, SW45, SW46, SW47, SW48 | Push | Switch:SW_Push | Library:Kailh_socket_PG1350 | ~
15 | 1 | SW49 | Reset | Switch:SW_Push | Button_Switch_SMD:SW_SPST_SKQG_WithStem | ~
16 | 1 | U1 | ATmega32U2 | MCU_Microchip_ATmega:ATmega32U2-A | Package_QFP:TQFP-32_7x7mm_P0.8mm | http://ww1.microchip.com/downloads/en/DeviceDoc/doc7799.pdf
17 | 1 | U2 | NCP1117 | Regulator_Linear:LM337_SOT223 | Package_TO_SOT_SMD:SOT-223
18 | 1 | X1 | 16Mhz | Device:Crystal | Crystal:Crystal_SMD_5032-2Pin_5.0x3.2mm | ~

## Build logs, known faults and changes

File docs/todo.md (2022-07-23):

# Todo

Para nuevas releases:

Propuesta para la version 1.1:

1. Polaridad en condensdores de la seccion de energia.
2. Hacer que todo el circuito este en 3.3v
3. Led para power con puente.
4. Led para Caps Lock (Caps),  Num Lock (NumLock).
5. Que sea barra espaciadora y no dos teclas.
6. Le ponemos un USB HUB?, con la idea de conectar el receptor de logitec del mouse y ahorrar puertos?.

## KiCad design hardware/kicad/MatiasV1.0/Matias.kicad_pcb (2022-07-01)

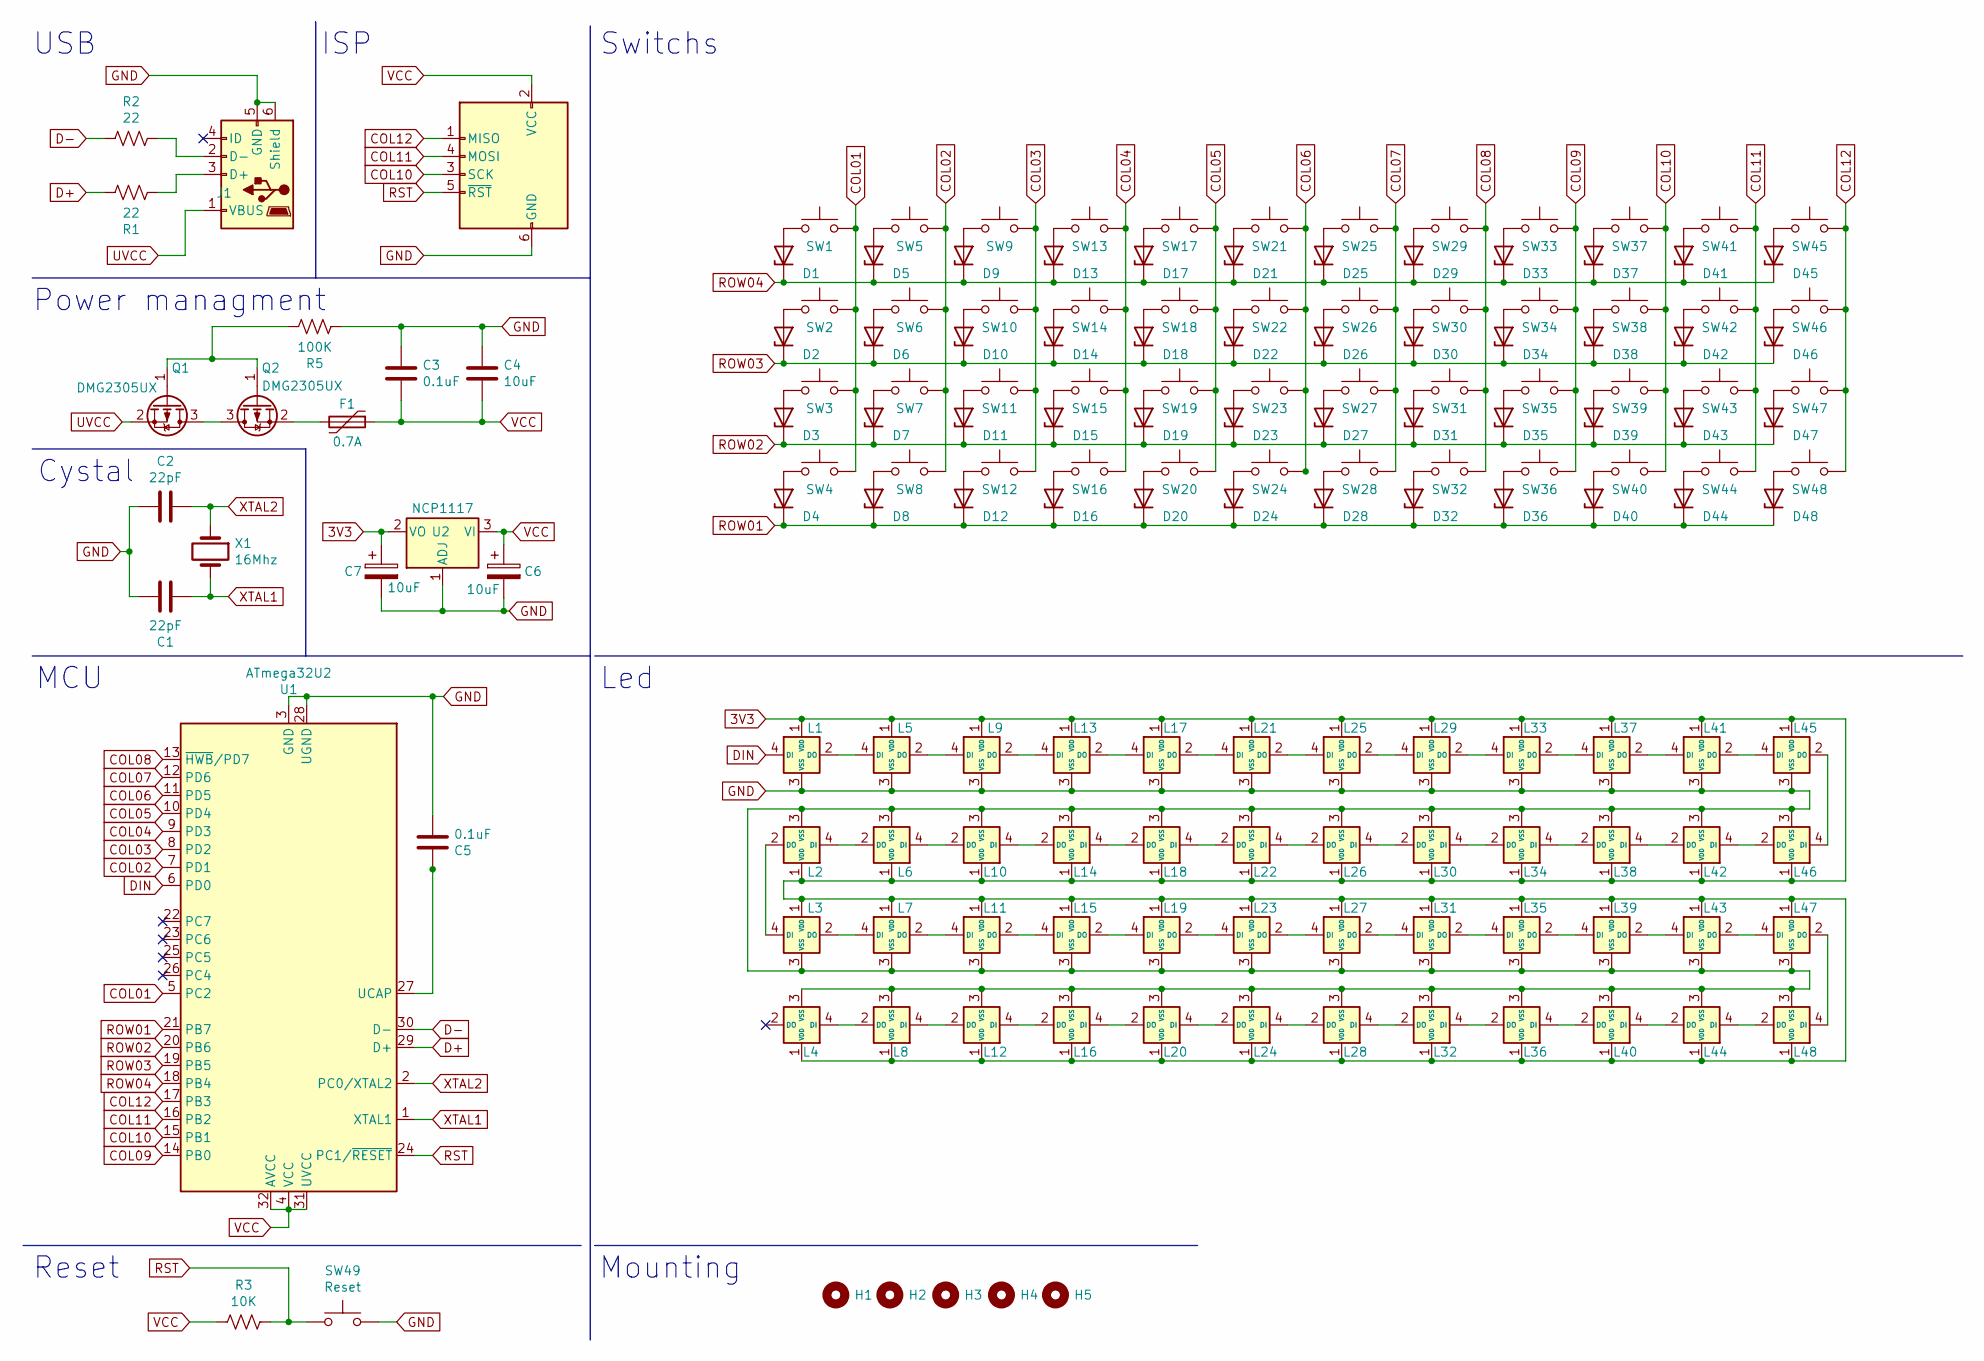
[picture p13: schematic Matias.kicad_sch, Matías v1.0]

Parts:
C1, C2: 22pF; C1206
C3, C5: 0.1uF; C1206
C4: 10uF; C1206
C6, C7: 10uF; CP_EIA-3216-18_Kemet-A
D1, D2, D3, D4, D5, D6, D7, D8, D9, D10, D11, D12, D13, D14, D15, D16, D17, D18, D19, D20, D21, D22, D23, D24, D25, D26, D27, D28, D29, D30, D31, D32, D33, D34, D35, D36, D37, D38, D39, D40, D41, D42, D43, D44, D45, D46, D47, D48: 1N47xxA; D1206
F1: 0.7A; R1206
H1, H2, H3, H4, H5: MountingHole; MountingHole_2.2mm_M2
ISP1: AVR-ISP-6; ISP
J1: USB Type B Mini; USB_Micro-B
L1, L2, L3, L4, L5, L6, L7, L8, L9, L10, L11, L12, L13, L14, L15, L16, L17, L18, L19, L20, L21, L22, L23, L24, L25, L26, L27, L28, L29, L30, L31, L32, L33, L34, L35, L36, L37, L38, L39, L40, L41, L42, L43, L44, L45, L46, L47, L48: SK6812MINI; SK6812-MINI-E
Q1, Q2: DMG2305UX; SOT-23
R1, R2: 22; R1206
R3: 10K; R1206
R5: 100K; R1206
SW1, SW2, SW3, SW4, SW5, SW6, SW7, SW8, SW9, SW10, SW11, SW12, SW13, SW14, SW15, SW16, SW17, SW18, SW19, SW20, SW21, SW22, SW23, SW24, SW25, SW26, SW27, SW28, SW29, SW30, SW31, SW32, SW33, SW34, SW35, SW36, SW37, SW38, SW39, SW40, SW41, SW42, SW43, SW44, SW45, SW46, SW47, SW48: Push; Kailh_socket_PG1350
SW49: Reset; SW_SPST_SKQG_WithStem
U1: ATmega32U2; TQFP-32_7x7mm_P0.8mm
U2: NCP1117; SOT-223
X1: 16Mhz; Crystal_SMD_5032-2Pin_5.0x3.2mm

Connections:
3V3: C7.1, L1.1 (VDD), L2.1 (VDD), L3.1 (VDD), L4.1 (VDD), L5.1 (VDD), L6.1 (VDD), L7.1 (VDD), L8.1 (VDD), L9.1 (VDD), L10.1 (VDD), L11.1 (VDD), L12.1 (VDD), L13.1 (VDD), L14.1 (VDD), L15.1 (VDD), L16.1 (VDD), L17.1 (VDD), L18.1 (VDD), L19.1 (VDD), L20.1 (VDD), L21.1 (VDD), L22.1 (VDD), L23.1 (VDD), L24.1 (VDD), L25.1 (VDD), L26.1 (VDD), L27.1 (VDD), L28.1 (VDD), L29.1 (VDD), L30.1 (VDD), L31.1 (VDD), L32.1 (VDD), L33.1 (VDD), L34.1 (VDD), L35.1 (VDD), L36.1 (VDD), L37.1 (VDD), L38.1 (VDD), L39.1 (VDD), L40.1 (VDD), L41.1 (VDD), L42.1 (VDD), L43.1 (VDD), L44.1 (VDD), L45.1 (VDD), L46.1 (VDD), L47.1 (VDD), L48.1 (VDD), U2.2 (VO)
COL01: SW1.2, SW2.2, SW3.2, SW4.2, U1.5 (PC2)
COL02: SW5.2, SW6.2, SW7.2, SW8.2, U1.7 (PD1)
COL03: SW9.2, SW10.2, SW11.2, SW12.2, U1.8 (PD2)
COL04: SW13.2, SW14.2, SW15.2, SW16.2, U1.9 (PD3)
COL05: SW17.2, SW18.2, SW19.2, SW20.2, U1.10 (PD4)
COL06: SW21.2, SW22.2, SW23.2, SW24.2, U1.11 (PD5)
COL07: SW25.2, SW26.2, SW27.2, SW28.2, U1.12 (PD6)
COL08: SW29.2, SW30.2, SW31.2, SW32.2, U1.13 (~HWB/PD7)
COL09: SW33.2, SW34.2, SW35.2, SW36.2, U1.14 (PB0)
COL10: ISP1.3 (SCK), SW37.2, SW38.2, SW39.2, SW40.2, U1.15 (PB1)
COL11: ISP1.4 (MOSI), SW41.2, SW42.2, SW43.2, SW44.2, U1.16 (PB2)
COL12: ISP1.1 (MISO), SW45.2, SW46.2, SW47.2, SW48.2, U1.17 (PB3)
D+: R1.1, U1.29 (D+)
D-: R2.2, U1.30 (D-)
DIN: L1.4 (DI), U1.6 (PD0)
GND: C1.1, C2.2, C3.1, C4.1, C5.2, C6.2, C7.2, ISP1.6 (GND), J1.5 (GND), J1.6 (Shield), L1.3 (VSS), L2.3 (VSS), L3.3 (VSS), L4.3 (VSS), L5.3 (VSS), L6.3 (VSS), L7.3 (VSS), L8.3 (VSS), L9.3 (VSS), L10.3 (VSS), L11.3 (VSS), L12.3 (VSS), L13.3 (VSS), L14.3 (VSS), L15.3 (VSS), L16.3 (VSS), L17.3 (VSS), L18.3 (VSS), L19.3 (VSS), L20.3 (VSS), L21.3 (VSS), L22.3 (VSS), L23.3 (VSS), L24.3 (VSS), L25.3 (VSS), L26.3 (VSS), L27.3 (VSS), L28.3 (VSS), L29.3 (VSS), L30.3 (VSS), L31.3 (VSS), L32.3 (VSS), L33.3 (VSS), L34.3 (VSS), L35.3 (VSS), L36.3 (VSS), L37.3 (VSS), L38.3 (VSS), L39.3 (VSS), L40.3 (VSS), L41.3 (VSS), L42.3 (VSS), L43.3 (VSS), L44.3 (VSS), L45.3 (VSS), L46.3 (VSS), L47.3 (VSS), L48.3 (VSS), R5.2, SW49.2, U1.3 (GND), U1.28 (UGND), U2.1 (ADJ); also elsewhere on the board
unnamed: C5.1, U1.27 (UCAP)
unnamed: D1.2 (A), SW1.1
unnamed: D2.2 (A), SW2.1
unnamed: D3.2 (A), SW3.1
unnamed: D4.2 (A), SW4.1
unnamed: D5.2 (A), SW5.1
unnamed: D6.2 (A), SW6.1
unnamed: D7.2 (A), SW7.1
unnamed: D8.2 (A), SW8.1
unnamed: D9.2 (A), SW9.1
unnamed: D10.2 (A), SW10.1
unnamed: D11.2 (A), SW11.1
unnamed: D12.2 (A), SW12.1
unnamed: D13.2 (A), SW13.1
unnamed: D14.2 (A), SW14.1
unnamed: D15.2 (A), SW15.1
unnamed: D16.2 (A), SW16.1
unnamed: D17.2 (A), SW17.1
unnamed: D18.2 (A), SW18.1
unnamed: D19.2 (A), SW19.1
unnamed: D20.2 (A), SW20.1
unnamed: D21.2 (A), SW21.1
unnamed: D22.2 (A), SW22.1
unnamed: D23.2 (A), SW23.1
unnamed: D24.2 (A), SW24.1
unnamed: D25.2 (A), SW25.1
unnamed: D26.2 (A), SW26.1
unnamed: D27.2 (A), SW27.1
unnamed: D28.2 (A), SW28.1
unnamed: D29.2 (A), SW29.1
unnamed: D30.2 (A), SW30.1
unnamed: D31.2 (A), SW31.1
unnamed: D32.2 (A), SW32.1
unnamed: D33.2 (A), SW33.1
unnamed: D34.2 (A), SW34.1
unnamed: D35.2 (A), SW35.1
unnamed: D36.2 (A), SW36.1
unnamed: D37.2 (A), SW37.1
unnamed: D38.2 (A), SW38.1
unnamed: D39.2 (A), SW39.1
unnamed: D40.2 (A), SW40.1
unnamed: D41.2 (A), SW41.1
unnamed: D42.2 (A), SW42.1
unnamed: D43.2 (A), SW43.1
unnamed: D44.2 (A), SW44.1
unnamed: D45.2 (A), SW45.1
unnamed: D46.2 (A), SW46.1
unnamed: D47.2 (A), SW47.1
unnamed: D48.2 (A), SW48.1
unnamed: F1.2, Q2.2 (S)
unnamed: J1.2 (D-), R2.1
unnamed: J1.3 (D+), R1.2
unnamed: L1.2 (DO), L5.4 (DI)
unnamed: L2.2 (DO), L3.4 (DI)
unnamed: L2.4 (DI), L6.2 (DO)
unnamed: L3.2 (DO), L7.4 (DI)
unnamed: L4.4 (DI), L8.2 (DO)
unnamed: L5.2 (DO), L9.4 (DI)
unnamed: L6.4 (DI), L10.2 (DO)
unnamed: L10.4 (DI), L14.2 (DO)
unnamed: L11.2 (DO), L15.4 (DI)
unnamed: L7.2 (DO), L11.4 (DI)
unnamed: L8.4 (DI), L12.2 (DO)
unnamed: L12.4 (DI), L16.2 (DO)
unnamed: L13.2 (DO), L17.4 (DI)
unnamed: L9.2 (DO), L13.4 (DI)
unnamed: L14.4 (DI), L18.2 (DO)
unnamed: L15.2 (DO), L19.4 (DI)
unnamed: L16.4 (DI), L20.2 (DO)
unnamed: L17.2 (DO), L21.4 (DI)
unnamed: L18.4 (DI), L22.2 (DO)
unnamed: L19.2 (DO), L23.4 (DI)
unnamed: L20.4 (DI), L24.2 (DO)
unnamed: L21.2 (DO), L25.4 (DI)
unnamed: L22.4 (DI), L26.2 (DO)
unnamed: L23.2 (DO), L27.4 (DI)
unnamed: L24.4 (DI), L28.2 (DO)
unnamed: L25.2 (DO), L29.4 (DI)
unnamed: L26.4 (DI), L30.2 (DO)
unnamed: L27.2 (DO), L31.4 (DI)
unnamed: L28.4 (DI), L32.2 (DO)
unnamed: L29.2 (DO), L33.4 (DI)
unnamed: L30.4 (DI), L34.2 (DO)
unnamed: L31.2 (DO), L35.4 (DI)
unnamed: L32.4 (DI), L36.2 (DO)
unnamed: L33.2 (DO), L37.4 (DI)
unnamed: L34.4 (DI), L38.2 (DO)
unnamed: L35.2 (DO), L39.4 (DI)
unnamed: L36.4 (DI), L40.2 (DO)
unnamed: L37.2 (DO), L41.4 (DI)
unnamed: L38.4 (DI), L42.2 (DO)
unnamed: L39.2 (DO), L43.4 (DI)
unnamed: L40.4 (DI), L44.2 (DO)
unnamed: L41.2 (DO), L45.4 (DI)
unnamed: L42.4 (DI), L46.2 (DO)
unnamed: L43.2 (DO), L47.4 (DI)
unnamed: L44.4 (DI), L48.2 (DO)
unnamed: L45.2 (DO), L46.4 (DI)
unnamed: L47.2 (DO), L48.4 (DI)
unnamed: Q1.1 (G), Q2.1 (G), R5.1
unnamed: Q1.3 (D), Q2.3 (D)
ROW01: D4.1 (K), D8.1 (K), D12.1 (K), D16.1 (K), D20.1 (K), D24.1 (K), D28.1 (K), D32.1 (K), D36.1 (K), D40.1 (K), D44.1 (K), D48.1 (K), U1.21 (PB7)
ROW02: D3.1 (K), D7.1 (K), D11.1 (K), D15.1 (K), D19.1 (K), D23.1 (K), D27.1 (K), D31.1 (K), D35.1 (K), D39.1 (K), D43.1 (K), D47.1 (K), U1.20 (PB6)
ROW03: D2.1 (K), D6.1 (K), D10.1 (K), D14.1 (K), D18.1 (K), D22.1 (K), D26.1 (K), D30.1 (K), D34.1 (K), D38.1 (K), D42.1 (K), D46.1 (K), U1.19 (PB5)
ROW04: D1.1 (K), D5.1 (K), D9.1 (K), D13.1 (K), D17.1 (K), D21.1 (K), D25.1 (K), D29.1 (K), D33.1 (K), D37.1 (K), D41.1 (K), D45.1 (K), U1.18 (PB4)
RST: ISP1.5 (~RST), R3.2, SW49.1, U1.24 (PC1/~RESET); also elsewhere on the board
UVCC: J1.1 (VBUS), Q1.2 (S)
VCC: C3.2, C4.2, C6.1, F1.1, ISP1.2 (VCC), R3.1, U1.4 (VCC), U1.31 (UVCC), U1.32 (AVCC), U2.3 (VI)
XTAL1: C1.2, U1.1 (XTAL1), X1.2
XTAL2: C2.1, U1.2 (PC0/XTAL2), X1.1

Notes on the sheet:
USB
Power managment
MCU
Reset
Mounting
Led
ISP
Switchs
Cystal

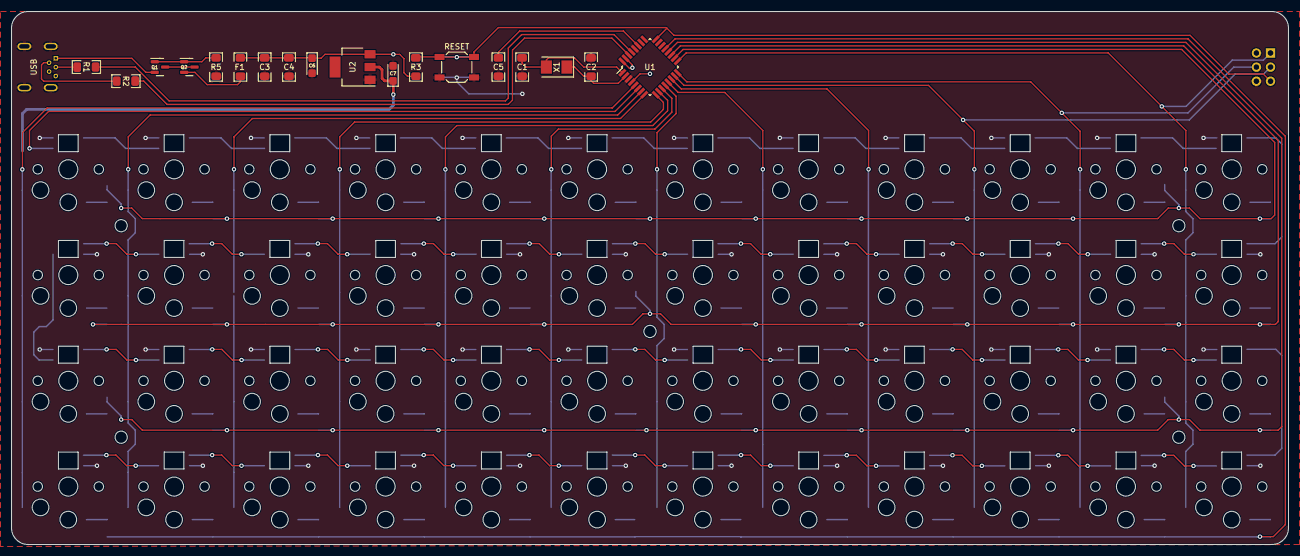
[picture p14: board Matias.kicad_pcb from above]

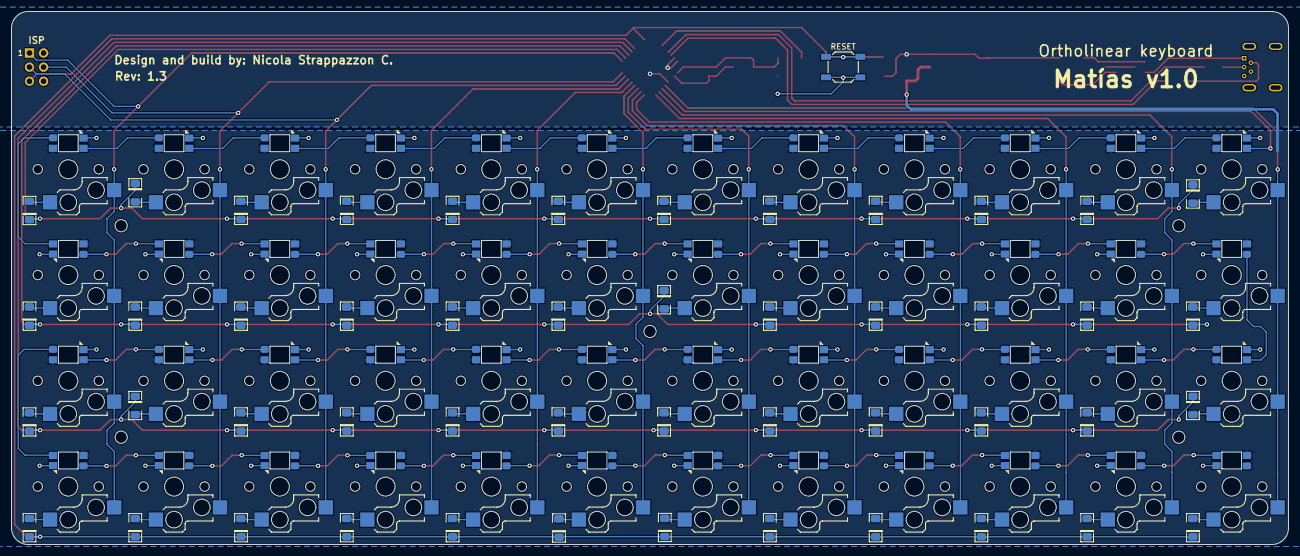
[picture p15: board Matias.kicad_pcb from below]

Board: 2 copper layers, 230.0 x 96.0 mm, 170 parts (50 on the bottom side), 127 nets.

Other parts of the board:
SW49#2: Reset; SW_SPST_SKQG_WithStem

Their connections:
GND: SW49#2.2; also elsewhere on the board
RST: SW49#2.1; also elsewhere on the board

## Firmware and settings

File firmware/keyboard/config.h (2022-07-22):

#pragma once

#include "config_common.h"

/* USB Device descriptor parameter */
#define VENDOR_ID       0xFEED
#define PRODUCT_ID      0x6060
#define MANUFACTURER    NSC
#define PRODUCT         Matias
#define DEVICE_VER      0x0001 // V1.0

/* key matrix size */
#define MATRIX_ROWS 4
#define MATRIX_COLS 12

/* key matrix pins */
#define MATRIX_ROW_PINS { B4,B5,B6,B7 }
#define MATRIX_COL_PINS { C2,D1,D2,D3,D4,D5,D6,D7,B0,B1,B2,B3 }
#define UNUSED_PINS

/* COL2ROW or ROW2COL */
#define DIODE_DIRECTION COL2ROW

/* Set 0 if debouncing isn't needed */
#define DEBOUNCE 5

/* BACKLIGHT */
#define RGB_DI_PIN D0
#define RGBLED_NUM 48
#define RGBLIGHT_LIMIT_VAL 20
#define RGBLIGHT_SLEEP

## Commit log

2022-07-01 feat(kicad) add project
    [Matias.kicad_pcb, Matias.kicad_sch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]
2022-07-01 feat(bom) add file and datasheets.
    [Matias.csv]
2022-07-22 feat(doc) update.
    [Matias.csv, Matias.kicad_pcb, Matias.kicad_sch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]
